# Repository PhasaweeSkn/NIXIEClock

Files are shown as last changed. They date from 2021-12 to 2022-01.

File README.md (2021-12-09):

# NIXIEClock  
 
 ## Conceptual Design


## Pin Assign


## Task (Planned)


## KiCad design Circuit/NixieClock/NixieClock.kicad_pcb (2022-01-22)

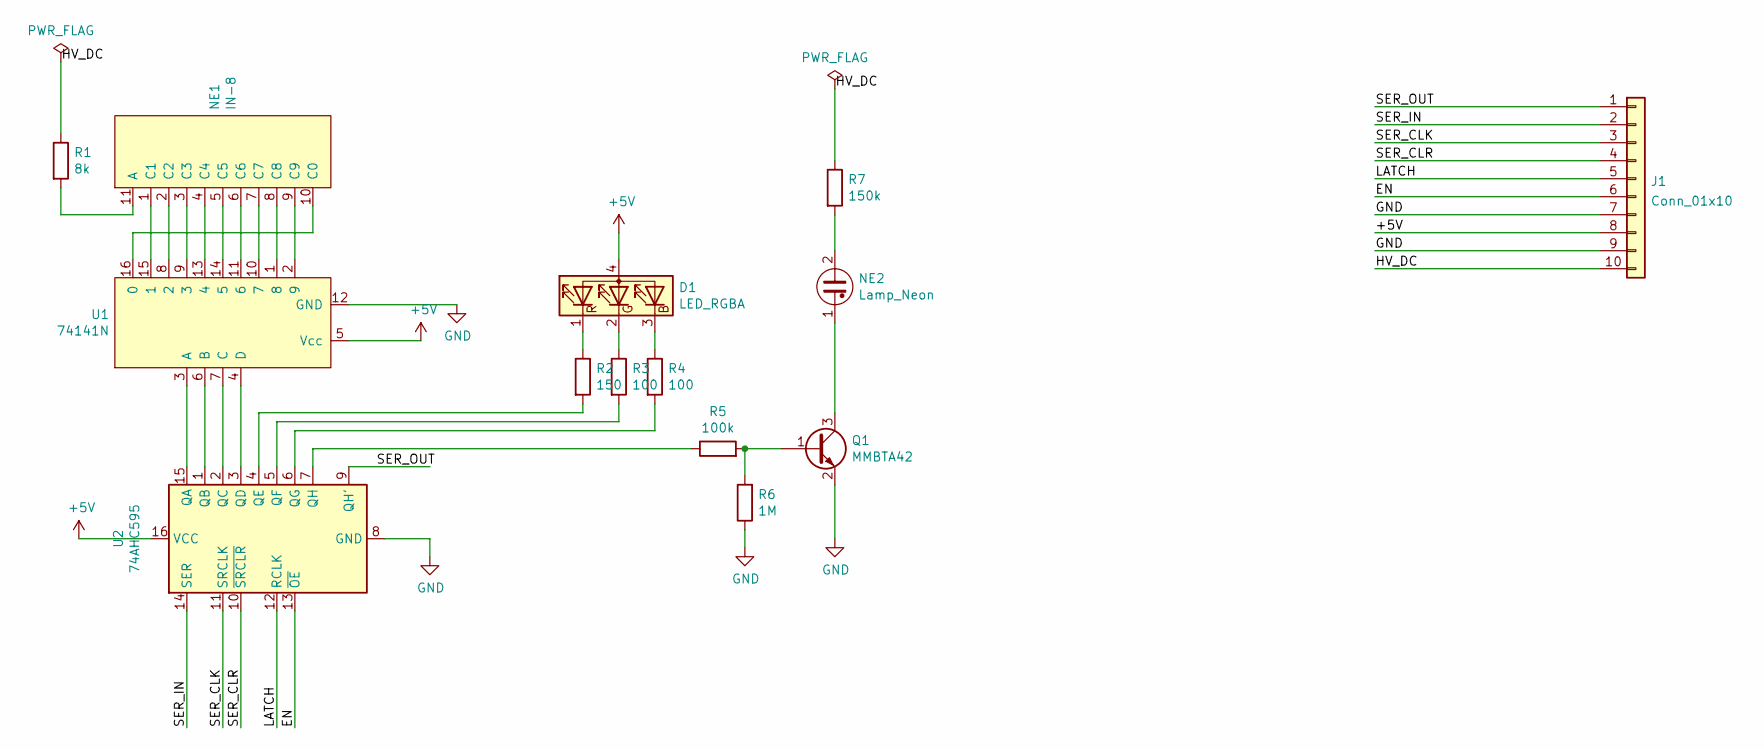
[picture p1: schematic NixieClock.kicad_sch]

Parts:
D1: LED_RGBA; LED_SK6805_PLCC4_2.4x2.7mm_P1.3mm
J1: Conn_01x10; JST_PH_B10B-PH-SM4-TB_1x10-1MP_P2.00mm_Vertical
NE1: IN-8
NE2: Lamp_Neon; R_Axial_DIN0204_L3.6mm_D1.6mm_P7.62mm_Horizontal
Q1: MMBTA42; SOT-23
R1: 8k; R_1206_3216Metric_Pad1.30x1.75mm_HandSolder
R2: 150; R_0603_1608Metric_Pad0.98x0.95mm_HandSolder
R3, R4: 100; R_0603_1608Metric_Pad0.98x0.95mm_HandSolder
R5: 100k; R_0805_2012Metric_Pad1.20x1.40mm_HandSolder
R6: 1M; R_0805_2012Metric_Pad1.20x1.40mm_HandSolder
R7: 150k; R_1206_3216Metric_Pad1.30x1.75mm_HandSolder
U1: 74141N; DIP-16_W7.62mm
U2: 74AHC595; SOIC-16_3.9x9.9mm_P1.27mm

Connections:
+5V: D1.4 (A), J1.8, U1.5 (Vcc), U2.16 (VCC)
/EN: J1.6, U2.13 (~OE)
/HV_DC: J1.10, R1.1, R7.1
/LATCH: J1.5, U2.12 (RCLK)
/SER_CLK: J1.3, U2.11 (SRCLK)
/SER_CLR: J1.4, U2.10 (~SRCLR)
/SER_IN: J1.2, U2.14 (SER)
/SER_OUT: J1.1, U2.9 (QH')
GND: J1.7, J1.9, Q1.2 (E), R6.1, U1.12 (GND), U2.8 (GND)
unnamed: D1.1 (RK), R2.1
unnamed: D1.2 (GK), R3.1
unnamed: D1.3 (BK), R4.1
unnamed: NE1.1 (C1), U1.15 (1)
unnamed: NE1.2 (C2), U1.8 (2)
unnamed: NE1.3 (C3), U1.9 (3)
unnamed: NE1.4 (C4), U1.13 (4)
unnamed: NE1.5 (C5), U1.14 (5)
unnamed: NE1.6 (C6), U1.11 (6)
unnamed: NE1.7 (C7), U1.10 (7)
unnamed: NE1.8 (C8), U1.1 (8)
unnamed: NE1.9 (C9), U1.2 (9)
unnamed: NE1.10 (C0), U1.16 (0)
unnamed: NE1.11 (A), R1.2
unnamed: NE2.1, Q1.3 (C)
unnamed: NE2.2, R7.2
unnamed: Q1.1 (B), R5.2, R6.2
unnamed: R2.2, U2.4 (QE)
unnamed: R3.2, U2.5 (QF)
unnamed: R4.2, U2.6 (QG)
unnamed: R5.1, U2.7 (QH)
unnamed: U1.3 (A), U2.15 (QA)
unnamed: U1.4 (D), U2.3 (QD)
unnamed: U1.6 (B), U2.1 (QB)
unnamed: U1.7 (C), U2.2 (QC)

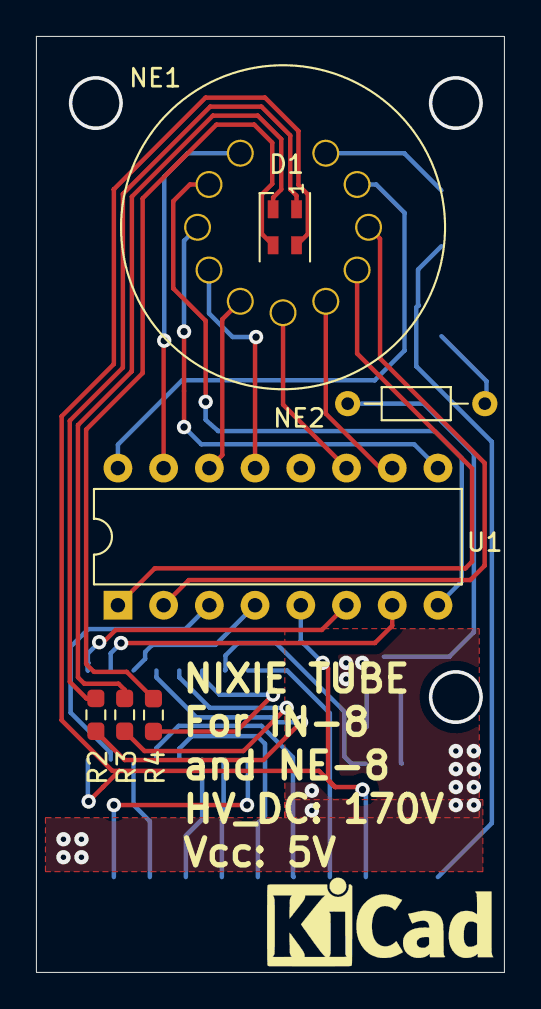
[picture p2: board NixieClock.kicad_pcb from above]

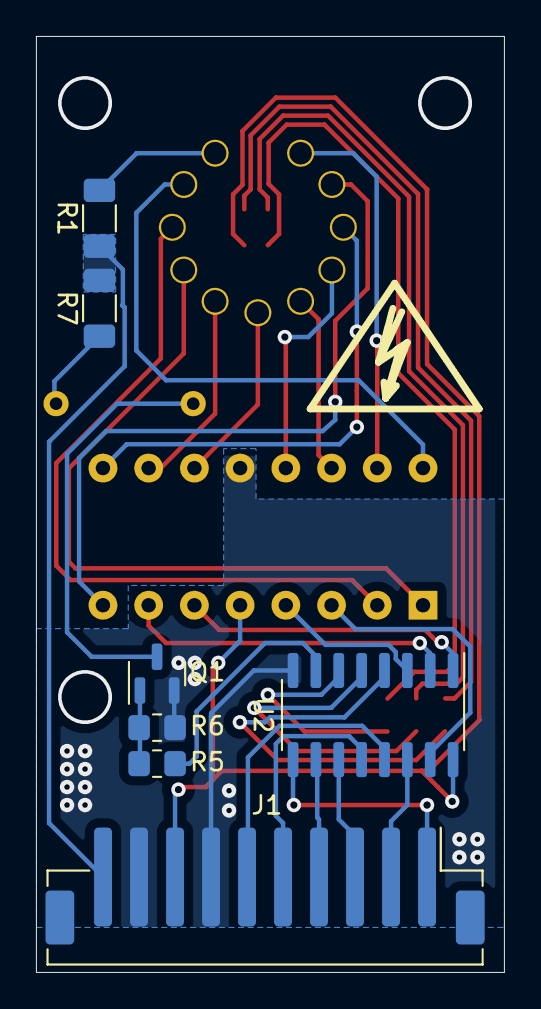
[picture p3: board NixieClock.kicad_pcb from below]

Board: 2 copper layers, 26.0 x 52.0 mm, 14 parts (7 on the bottom side), 34 nets.

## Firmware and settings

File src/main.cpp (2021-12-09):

#include <Arduino.h>
#include <WiFi.h>



//------------------------------- Local Library Include Start ------------------------------------//

#include "web_page.hpp"
#include "lamp_drive.hpp"

//-------------------------------- Local Library Include End -------------------------------------//



//--------------------------------- Defination Macro Start ---------------------------------------//

#define SERIAL_BAUD   115200  // Console baud rate (use for debug)

#define WIFI_AP_SSID  "HELLO_NIXIE"
#define WIFI_AP_PASS  "Nixie01!"

//--------------------------------- Defination Macro END------------------------------------------//



//--------------------------------- Global Variable Start ----------------------------------------//

TaskHandle_t taskUpdateLamp_handler;

//--------------------------------- Global Variable End ------------------------------------------//



//--------------------------------- Function Prototype Start -------------------------------------//

uint8_t peripheral_init(void);

//--------------------------------- Function Prototype End ---------------------------------------//



void setup() {

  // TODO: To Complete INIT PERIPHERAL
  peripheral_init();

  // TODO: LOAD PARM from internal memory

  // TODO: WEB SERVER INIT
  webserver_init();

  // TODO: OTHER TASK CREATE

  // TODO: To complete "TaskUpdateLamp"
  xTaskCreatePinnedToCore(
                  taskUpdateLamp,           /* Task function. */
                  "TaskUpdateLamp",         /* name of task. */
                  10000,                    /* Stack size of task */
                  NULL,                     /* parameter of the task */
                  1,                        /* priority of the task */
                  &taskUpdateLamp_handler,  /* Task handle to keep track of created task */
                  1);                       /* pin task to core 0 */          

}



void loop() {
  taskYIELD();  //NOP
}



// FUNCTION:    peripheral_init
// DESCRIPTION: 
//              Init ALL Peripheral, UART, I2C, WIFI,
// PARAM:       NO ARGUMENT
// RETURN:      UINT8, 1 = Complete Initial
uint8_t peripheral_init(void) {

  // UART INIT
  Serial.begin(SERIAL_BAUD);

  // TODO: PWM, I2C, WIFI (AP, STA)

  return 1;

}

// FUNCTION:    wifi_init
// DESCRIPTION: 
//              Config WIFI; AP and STA
// PARAM:       NO ARGUMENT
// RETURN:      UINT8, 1 = Complete Initial
uint8_t wifi_init(){

  // Config WiFi as AP and STA mode
  WiFi.mode(WIFI_MODE_APSTA);

  // Config AP wifi
  WiFi.softAP(WIFI_AP_SSID, WIFI_AP_PASS);

  // TODO: STA config
  // Ex. USE string arg; WiFi.begin(ssid.c_str(),pass.c_str());

  return 1;
}

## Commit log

2021-12-09 Update README.md
    Added Conceptual Design, Pin Assign, Task
2021-12-09 Added Skeleton of Circuit to Project
    [NixieClock.kicad_pcb, NixieClock.sch]
2021-12-09 Added IN-8 and 74141 to Library
    [NixieClock.kicad_pcb]
2021-12-18 Place 74595 in Circuit
    [NixieClock.sch]
2021-12-23 Added Datasheet; Neon, Nixie, LED, BCD2DEC
2021-12-23 Added Calculate Sheet
    [CalculationSheet.xlsx]
2021-12-23 Added Neon, LED and miscellaneous
    [NixieClock.sch]
2022-01-08 Ignore Kicad Backup Files
2022-01-08 Added Datasheet HV Driver
2022-01-08 Migrate to Kicad6
    [NixieClock.kicad_pcb, NixieClock.kicad_sch]
2022-01-09 Set Conn Pin 4 as GND, Rule, and Board Shape
    [NixieClock.kicad_pcb, NixieClock.kicad_sch]
2022-01-11 Complete Route NIXIE tube to Driver
    [NixieClock.kicad_pcb]
2022-01-13 Complete Route
    [NixieClock.kicad_pcb]
2022-01-22 Generate Gerber File
    [NixieClock-B_Cu.gbl, NixieClock-B_Mask.gbs, NixieClock-B_Paste.gbp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]
